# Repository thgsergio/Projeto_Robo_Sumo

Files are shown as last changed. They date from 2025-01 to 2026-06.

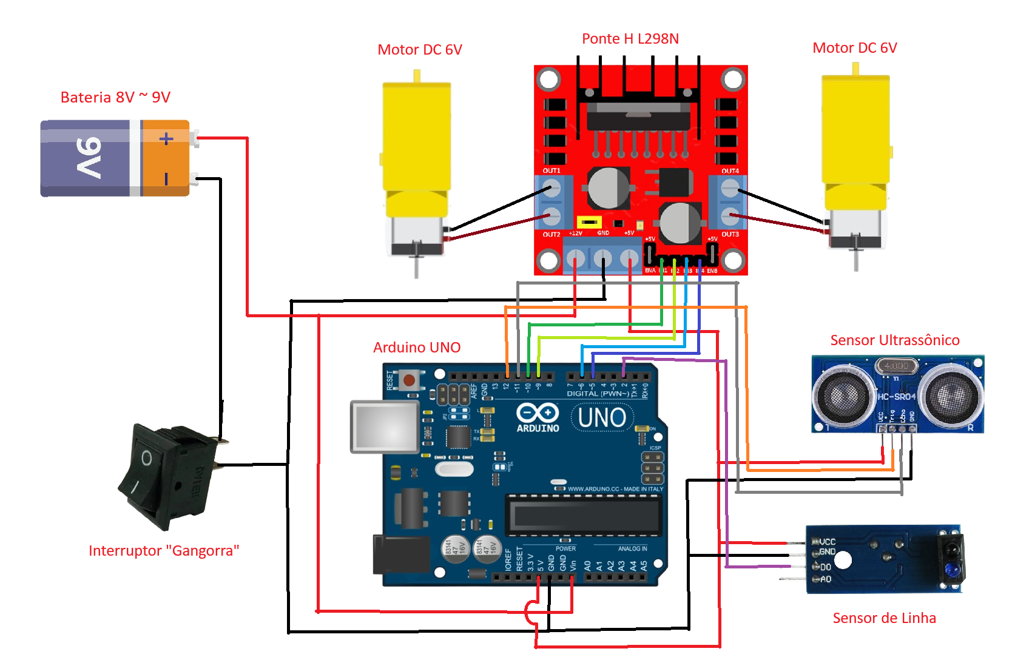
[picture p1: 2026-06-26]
Prototipo_02/Circuito Robô Sumô.png

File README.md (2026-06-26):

# Projeto Robô Sumô



Ei, sabe aquelas competições de sumô que ocorrem nos ringues entre duas pessoas? E se usássemos robôs no lugar para competirem entre si?...

## Conceito

O Projeto Robô-Sumô é um projeto de extensão fornecido pela Universidade Federal da Paraíba (UFPB).  Orientador: Prof. Dr. Ruy Alberto Pisani Altafim

Esse repositório contém arquivos de modelagem 3D do robô-sumo construído. Os principais pontos focados no desenvolvimento do modelo consistem em atingir um modelo estrutural simples e barato que facilite a montagem do robô e que, ao mesmo tempo, ele possa se movimentar de forma eficiente para empurrar seus adversários para fora da arena. 

Esse repositório também contém uma variedade de arquivos de extensão ".ino" que podem ser usados para testar os componentes eletrônicos usados no robô, bem como uma lógica de movimentação que funciona com bases em classes, feitas em C++.

Por fim, ele também contém imagens esquemáticas que representam o circuito eletrônico usado no robô-sumô, detalhando quais conexões são feitas em quais componentes. 

## Objetivos

Um dos focos do projeto foi utilizar o esse robô no setor escolar para o ensino de robótica, expandindo essa temática para escolas onde o acesso a essa tecnologia não é tão abrangente quanto em regiões mais desenvolvidas.

Outro objetivo do projeto é construir robôs-sumôs para serem usados em competições de robótica, seja em âmbito local, regional ou até nacional (quem sabe, né?).

---

No mais, espero que se divirta no desenvolvimento do seu próprio robô!

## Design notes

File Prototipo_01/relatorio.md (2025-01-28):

## Relatório 01 - Robô-Sumô

###### Autor: Thiago Sergio

### - Introdução

O presente relatório, que possui relação com o primeiro protótipo desenvolvido utilizando impressão 3D (imagem acima), possui como objetivo destacar as vantagens e desvantagens do modelo identificados pelo autor desse texto, bem como apontar possíveis melhorias que possam ser aplicadas nas próximas impressões. 

Os procedimentos metodológicos usados para a composição dessa pesquisa baseiam-se em testes experimentais a respeito do desempenho do modelo em atividades essenciais que o robô-sumô deve realizar, tais como andar para frente, parar, girar, etc. Em resposta às possíveis falhas encontradas, será proposto novos protótipos e/ou atualizações no código-fonte de seu funcionamento a fim de aperfeiçoar cada vez mais o robô, levando em conta, também, o foco em abaixar seu custo de produção para que seu custo-benefício seja satisfatório para os objetivos do projeto.

### - Possíveis Falhas Identificadas

1. *Largura de 0,5cm*: para meios de economia de material, é provável que 0,4cm ou 0,3cm sejam o suficiente.
2. *Peças em relevo*: para meios de economia de tempo e gasto, recomenda-se que as peças estejam o mais planificadas possível.
3. *Hardware solto*: para meios de segurança do equipamento, deve-se inserir algum meio para que as peças fiquem fixas no modelo, tanto utilizando parafusos (nesse caso, mudanças no protótipo são necessárias) como por algum outro método que mostrar-se mais conveniente.
    1. OBS (Sensor de linha): uma alternativa para sua melhor fixação é a alteração do protótipo para que ele possa ser encaixado perfeitamente na peça.
4. *Encaixes entre as peças*: para meios de sustentação, os encaixes *devem* ser modificados, pois seus tamanhos são os mesmos, o que impossibilita que as peças de fato encaixem-se umas nas outras. Deve-se haver uma diferença de tamanho entre o encaixe "macho" e  o encaixe "fêmea" para o encaixe ser bem sucedido.
    1. OBS (Tamanho): pequenas variações de tamanho geram o risco de os encaixes ficarem tão frouxos ao ponto de as peças saírem facilmente. Nesse caso, deve-se aplicar certa preciso nas medições *ou* deve-se alterar a forma com a qual as peças se encaixam umas nas outras.
5. *Proporções do protótipo*: para meios de montagem, o atual protótipo aparenta ser pequeno demais para portar a quantidade de equipamentos de hardware usados no projeto.

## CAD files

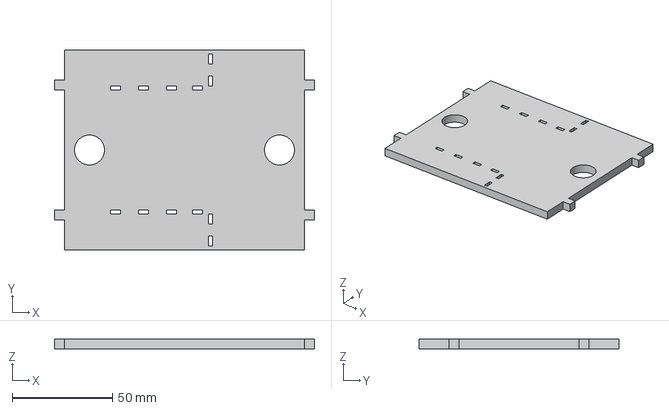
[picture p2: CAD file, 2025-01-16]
Prototipo_01/Prototipo_Robo_Sumo_V1/Base.3mf
130.0 x 100.0 x 5.00 mm

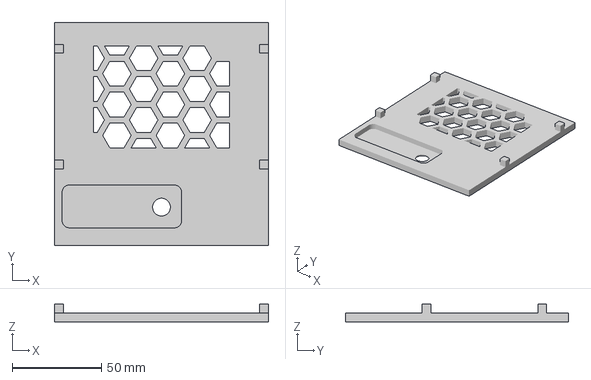
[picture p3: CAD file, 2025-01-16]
Prototipo_01/Prototipo_Robo_Sumo_V1/Lateral_Esquerda.3mf
120.0 x 125.0 x 10.0 mm

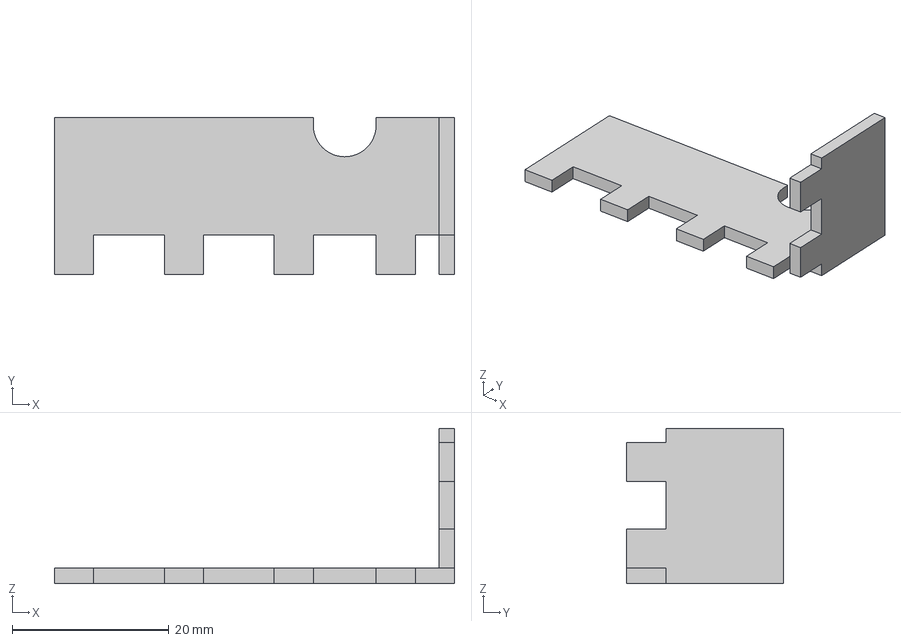
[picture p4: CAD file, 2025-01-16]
Prototipo_01/Prototipo_Robo_Sumo_V1/Base_Acoplar_01.3mf
51.0 x 20.0 x 19.8 mm

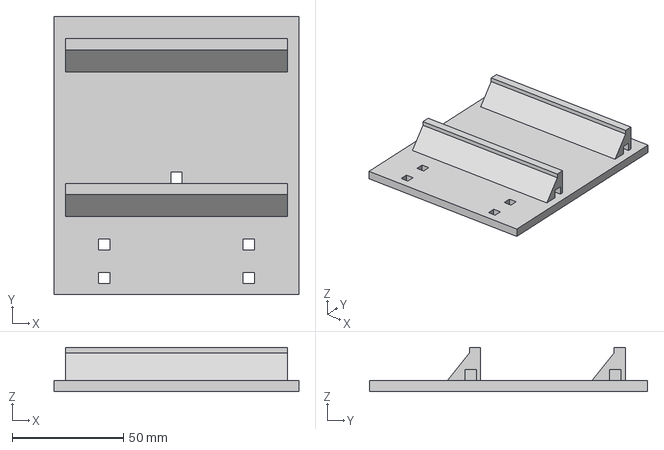
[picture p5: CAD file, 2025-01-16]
Prototipo_01/Prototipo_Robo_Sumo_V1/Atrás.3mf
110.0 x 125.0 x 20.0 mm

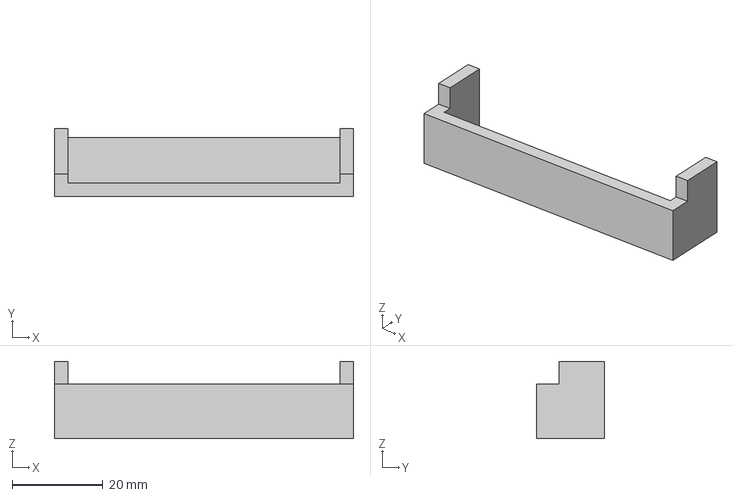
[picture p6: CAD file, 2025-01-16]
Prototipo_01/Prototipo_Robo_Sumo_V1/Frente_Acoplar.3mf
66.0 x 15.0 x 17.0 mm

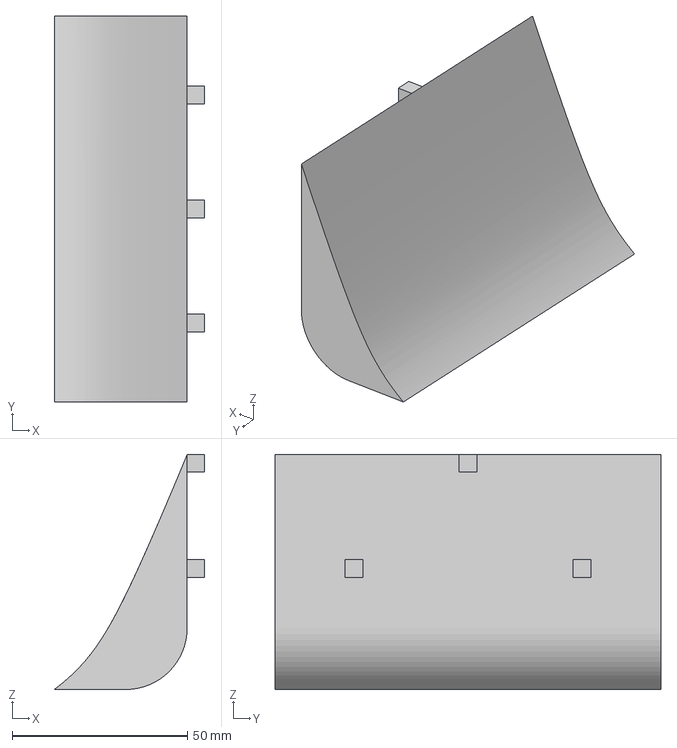
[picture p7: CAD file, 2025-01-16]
Prototipo_01/Prototipo_Robo_Sumo_V1/Rampa_2X.3mf
42.9 x 110.0 x 67.0 mm

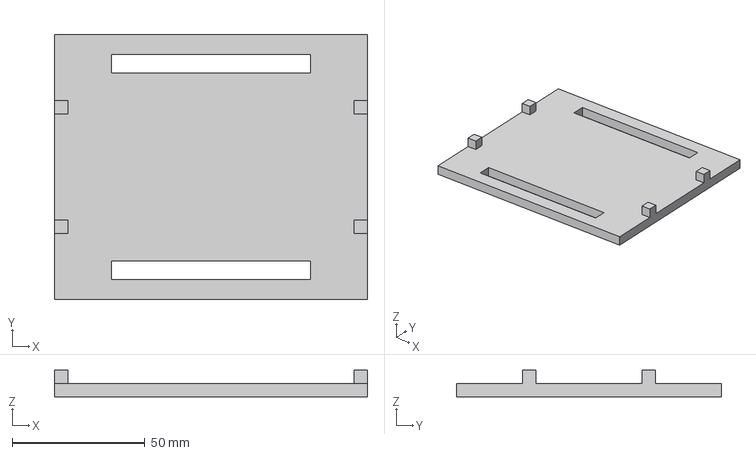
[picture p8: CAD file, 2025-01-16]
Prototipo_01/Prototipo_Robo_Sumo_V1/Topo.3mf
118.0 x 100.0 x 10.0 mm

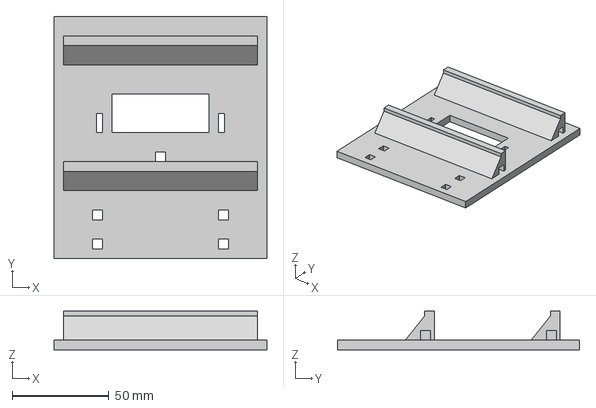
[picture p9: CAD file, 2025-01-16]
Prototipo_01/Prototipo_Robo_Sumo_V1/Frente.3mf
110.0 x 125.0 x 20.0 mm

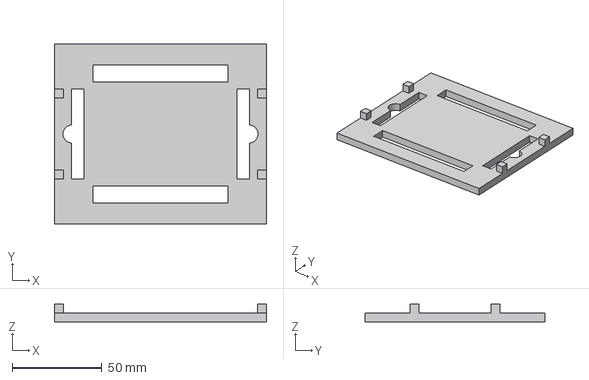
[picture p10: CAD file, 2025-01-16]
Prototipo_01/Prototipo_Robo_Sumo_V1/Meio.3mf
118.0 x 100.0 x 10.00 mm

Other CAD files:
Prototipo_01/Prototipo_Robo_Sumo_V1/Lateral_Direita.3mf
Prototipo_01/Prototipo_Robo_Sumo_V1/Base_Acoplar_02.3mf

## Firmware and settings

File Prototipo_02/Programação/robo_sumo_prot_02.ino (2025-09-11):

#include "classe_motor.h"

/* *** Definições dos Pinos *** */
#define MOTOR_A1 10
#define MOTOR_A2 9
#define MOTOR_B1 6
#define MOTOR_B2 5
#define ECHO 11
#define TRIGGER 12
#define pino_sensor 2 

// Criação dos objetos motor
DCMotor motor1; // Motor à esquerda, robô em 1ª pessoa como referencial
DCMotor motor2; // Motor à direita, robô em 1ª pessoa como referencial

// Protótipo das funções de movimentação do robô
void roboSetSpeed(int);
void roboForward();
void roboBackward();
void roboLeft();
void roboRight();
void roboStop();
void roboProcura();

// Variáveis importantes
int estadoSensor = 0;
int distancia_oponente = 0;

// Configurações iniciais
void setup() {
  motor1.setPin(MOTOR_A1, MOTOR_A2);
  motor2.setPin(MOTOR_B1, MOTOR_B2);
  pinMode(ECHO, INPUT);
  pinMode(TRIGGER, OUTPUT);
  pinMode(pino_sensor, INPUT);
  // Debug:
  Serial.begin(9600);
}

void loop() {
  estadoSensor = digitalRead(pino_sensor);
  //intervalo_atual = millis();

// Sensor ultrassônico
  digitalWrite(TRIGGER, HIGH);
  delayMicroseconds(20);
  digitalWrite(TRIGGER, LOW);
  distancia_oponente = (pulseIn(ECHO, HIGH)) * (0.034 / 2);

// Código para debugs
  Serial.print("Ultrassonic: ");
  Serial.println(distancia_oponente);

  Serial.print("Line sensor: ");
  Serial.println(estadoSensor);

  if (estadoSensor == 0){ // Enquanto o robô não vê a linha da arena...
    
    if(distancia_oponente <= 50){
        roboSetSpeed(250);

      while (estadoSensor != 1){
        estadoSensor = digitalRead(pino_sensor);
        roboForward();
      }

    }
    else {

      roboSetSpeed(120);

      // Procurar robô adversário
      roboProcura();

    }
  }

  else { // Identificou a linha: marcha ré e meia volta
    roboBackward();
    delay(1000);
    roboLeft();
    delay(1000);
  }
}

// Definição das funções de movimentação do robô
void roboSetSpeed(int speed){
  motor1.setSpeed(speed);
  motor2.setSpeed(speed);
}

void roboForward(){
  motor1.forward();
  motor2.forward();
}

void roboBackward(){
  motor1.backward();
  motor2.backward();
}

void roboLeft(){
  motor1.backward();
  motor2.forward();
}

void roboRight(){
  motor1.forward();
  motor2.backward();
}

void roboStop(){
  motor1.stop();
  motor2.stop();
}

void roboProcura(){
  roboForward();
  delay(300);
  roboLeft();
  delay(300);
}

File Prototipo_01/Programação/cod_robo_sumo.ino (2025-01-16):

/* *** Definições dos Pinos *** */
#define MOTOR_A1 10
#define MOTOR_A2 9
#define MOTOR_B1 6
#define MOTOR_B2 5
#define ECHO 11
#define TRIGGER 12
#define pino_sensor 2

/* *********** Variaveis importantes *********** */
int estado_sensor = 0;

int duracao_ult;
int distancia_ult;

int intervalo_troca_direcao = 1000;
int estado_motor = 0; // 0 = direita ; 1 = esquerda
int intervalo_anterior = 0;

int velocidade_motor;

/* *********** Configurações *********** */
void setup() {
  definir_velocidade(200);
  pinMode(pino_sensor, INPUT);
  pinMode(MOTOR_A1, OUTPUT);
  pinMode(MOTOR_A2, OUTPUT);
  pinMode(MOTOR_B1, OUTPUT);
  pinMode(MOTOR_B2, OUTPUT);
  pinMode(ECHO, INPUT);
  pinMode(TRIGGER, OUTPUT);
}

/* ************ Função Principal ************ */
void loop() {
  // Sensor de linha
  estado_sensor = digitalRead(pino_sensor);

  // Sensor Ultrassônico
  digitalWrite(TRIGGER, LOW);
  delayMicroseconds(2);
  digitalWrite(TRIGGER, HIGH);
  delayMicroseconds(10000);
  digitalWrite(TRIGGER, LOW);

  duracao_ult = pulseIn(ECHO, HIGH);
  distancia_ult = duracao_ult * (0.034 / 2);

  int tempo_atual = millis();
  
  // Loop principal
  if(estado_sensor == 0) {
    if (distancia_ult <= 50) {
      correr_frente();
      intervalo_anterior = tempo_atual;
    } else {
      procura_inimigos(estado_motor);
      if(tempo_atual - intervalo_anterior >= intervalo_troca_direcao){
        estado_motor = !estado_motor;
        intervalo_anterior = tempo_atual;
      }
    }
  } else if (estado_sensor == 1){
    correr_tras();
    intervalo_anterior = tempo_atual;
  }
}

void definir_velocidade(int valor){
  velocidade_motor = valor;
}

void correr_frente(){
  analogWrite(MOTOR_A1, velocidade_motor);
  analogWrite(MOTOR_B1, velocidade_motor);
  digitalWrite(MOTOR_A2, LOW);
  digitalWrite(MOTOR_B2, LOW);
}

void correr_tras(){
  digitalWrite(MOTOR_A1, LOW);
  digitalWrite(MOTOR_B1, LOW);
  analogWrite(MOTOR_A2, velocidade_motor);
  analogWrite(MOTOR_B2, velocidade_motor);
}

void virar_direita(){
  analogWrite(MOTOR_A1, velocidade_motor);
  digitalWrite(MOTOR_B1, LOW);
  digitalWrite(MOTOR_A2, LOW);
  analogWrite(MOTOR_B2, velocidade_motor);
}

void virar_esquerda(){
  digitalWrite(MOTOR_A1, LOW);
  analogWrite(MOTOR_B1, velocidade_motor);
  analogWrite(MOTOR_A2, velocidade_motor);
  digitalWrite(MOTOR_B2, LOW);
}

void procura_inimigos(int estado){
  if(estado)
    virar_direita();
  else
    virar_esquerda();
}

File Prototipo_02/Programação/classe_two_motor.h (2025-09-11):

#ifndef SUMO_ROBOT_CONTROLLER_H
#define SUMO_ROBOT_CONTROLLER_H

typedef enum{
    MOTOR_A,
    MOTOR_B
} Motors;

class SumoRobotController {
    private:
        // Motor A: esquerda
        // Motor B: direita
        int motor_a1, motor_a2, motor_b1, motor_b2;
        int speed;

        void motorForward(Motors motor){
            if(motor == MOTOR_A){
                analogWrite(motor_a1, speed);
                digitalWrite(motor_a2, LOW);
            }
            else if (motor == MOTOR_B){
                analogWrite(motor_b1, speed);
                digitalWrite(motor_b2, LOW);
            }
        }
        void motorBackward(Motors motor){
            if(motor == MOTOR_A){
                digitalWrite(motor_a1, LOW);
                analogWrite(motor_a2, speed);
            }
            else if (motor == MOTOR_B){
                digitalWrite(motor_b1, LOW);
                analogWrite(motor_b2, speed);
            }
        }
        void motorStop(Motors motor){
            if(motor == MOTOR_A){
                digitalWrite(motor_a1, LOW);
                digitalWrite(motor_a2, LOW);
            }
            else if(motor == MOTOR_B){
                digitalWrite(motor_b1, LOW);
                digitalWrite(motor_b2, LOW);
            }
        }

    public:
        SumoRobotController() : motor_a1(0), motor_a2(0), motor_b1(0), motor_b2(0) {
            speed = 200;
        }
        SumoRobotController(int a1, int a2, int b1, int b2) : speed(200) {
            setPins(a1, a2, b1, b2);
        }
        
        void setPins(int a1, int a2, int b1, int b2){
            motor_a1 = a1;
            motor_a2 = a2;
            motor_b1 = b1;
            motor_b2 = b2;
            pinMode(motor_a1, OUTPUT);
            pinMode(motor_a2, OUTPUT);
            pinMode(motor_b1, OUTPUT);
            pinMode(motor_b2, OUTPUT);
        }


        int getSpeed(){
            return speed;
        }

        void setSpeed(int spd){
            if (spd > 255){ // Valor máximo
                speed = 255;
            }
            else if (spd < 0){
                speed = 0;
            }
            else {
                speed = spd;
            }
        }


        void forward(){
            motorForward(MOTOR_A);
            motorForward(MOTOR_B);
        }

        void backward(){
            motorBackward(MOTOR_A);
            motorBackward(MOTOR_B);
        }

        void left(){
            motorBackward(MOTOR_A);
            motorForward(MOTOR_B);
        }

        void right(){
            motorForward(MOTOR_A);
            motorBackward(MOTOR_B);
        }

        void stop(){
            motorStop(MOTOR_A);
            motorStop(MOTOR_B);
        }

};

#endif

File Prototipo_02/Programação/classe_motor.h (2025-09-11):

#ifndef CLASSE_MOTOR_H
#define CLASSE_MOTOR_H

class DCMotor {
  private:
    int speed, in1, in2;
  
  public:

    // ============= Inicialização do Objeto =============
    DCMotor(){
      speed = 200;
    }
    DCMotor(int spd){
      if (spd > 255){
        speed = 255;
      }
      else if (spd < 0){
        speed = 0;
      }
      else {
        speed = spd;
      }
    }
    DCMotor(int pin1, int pin2) : DCMotor(){
      in1 = pin1;
      in2 = pin2;
    }
    DCMotor(int spd, int pin1, int pin2) : DCMotor(spd){
      in1 = pin1;
      in2 = pin2;
    }
    // ===================================================

    // Funções principais
    void setPin(int pin1, int pin2){
      in1 = pin1;
      in2 = pin2;
      pinMode(in1, OUTPUT);
      pinMode(in2, OUTPUT);
    }

    int getSpeed(){
      return speed;
    }

    void setSpeed(int spd){
      if (spd > 255){
        speed = 255;
      }
      else if (spd < 0){
        speed = 0;
      }
      else {
        speed = spd;
      }
    }

    void forward(){
      analogWrite(in1, speed);
      digitalWrite(in2, LOW);
    }

    void backward(){
      digitalWrite(in1, LOW);
      analogWrite(in2, speed);
    }

    void stop(){
      digitalWrite(in1, LOW);
      digitalWrite(in2, LOW);
    }
};

#endif

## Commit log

2025-01-16 Criando relatorio.md para o Protótipo 01
    O arquivo irá mostrar os pontos positivos e negativos do protótipo identificados por minha pessoa
2025-01-16 Adição dos arquivos do Protótipo 01
    [Atrás.3mf, Base.3mf, Base_Acoplar_01.3mf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]
2025-01-16 Adição do código inicial do Robô-Sumô
    Esse é o código que foi utilizado no arduino que constitui o robô-sumô
2025-01-16 Criando a primeira programação para o protótipo 02
    Por mais que seja pro 2º protótipo, também será aplicada no 1º protótipo para testes
2025-01-16 Carregando o header das novas linhas de código
2025-01-21 Primeiras movimentações (frente)(checkpoint)
    Basicamente, tentei fazer um algoritmo para ele ir para frente a cada 1 segundo, e parar a cada 1 segundo também. Ah, e também adicionei construtores com polimorfismo (sobrecarga de métodos) na class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
2025-01-21 Variável booleana de controle do robô
    Coloquei essa variável pra fazer a troca entre ficar parado ou andando a cada 1 segundo.
2025-01-21 Troca de direção do robô
    Bem, aqui o algoritmo é mais completo. A ideia é que o robô vá pra frente, gire 1 vez pra esquerda, 2x pra direita e mais 1x pra esquerda (sendo esta última girada com o objetivo de deixar o robô olh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
2025-01-22 Implementação do sensor ultrassônico
    Se o robô "ver" o inimigo, deverá andar para frente até ele chegar na borda da arena.
2025-01-28 Primeiras Impressões - Relatório 01
    Aqui, coloquei as possíveis falhas que eu pude detectar no protótipo atual, mas por se tratar de uma opinião própria única minha, talvez alguma "falha" possa ser desconsiderada no momento. É necessár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
2025-03-16 Circuito Robô Sumô
    Essa é a imagem do atual circuito utilizado no robô sumô!
2025-04-01 Atualização do código
    Retirei a parte complexa que eu tinha implementado anteriormente e tentei usar uma programação mais simples, pelo menos, por enquanto.
2025-04-03 Correção de Erros e Debug
    Adicionei códigos para fazer o debug dos sensores e corrigi o erro de o robô não parar de andar ao ver o inimigo (ele deveria parar quando visse a linha, e de fato agora ele consegue fazer isso :D)
    [robo_sumo_prot_02.ino]
2025-09-11 refactor: Inserção de alguns comentários para guia e novo construtor para a classe
2025-09-11 feat: Código de teste dos motores
2025-09-11 feat: Nova classe para controlar dois motores simultaneamente
2025-09-12 feat: Código de teste do sensor ultrassônico
2025-09-12 feat: Código de teste do sensor de linha
2025-09-12 feat: Novo código de movimentação do robô usando a nova biblioteca!
2026-06-26 fix: Correção do circuito elétrico do projeto
    Empiricamente, usar uma bateria de 9V se mostrou mais eficiente do que tensões mais baixas, por conta da queda de tensão de cerca de 2V que a ponte H causa na tensão de entrada. Assim, a tensão real que chega no circuito estava abaixo do esperado, justamente por conta dessa queda. Por conta disso, apesar de 8V ser melhor, comercialmente a bateria de 9V é mais comum de ser encontrada. Vale apenas testar para verificar se, a longo prazo, usar essa bateria é viável para os motores, ou seja, se não fará eles se desgastarem mais rápido do que o esperado.
2026-06-26 fix: Correção de label no diagrama elétrico
